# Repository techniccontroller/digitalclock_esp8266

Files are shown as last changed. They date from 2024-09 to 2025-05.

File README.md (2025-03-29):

# DigitalClock

DigitalClick with Neopixel LEDs and ESP8266

More details on my website: https://techniccontroller.com/diy-digitalclock-with-neopixel-led-and-esp8266/ 

## Features
- receives time updates via a NTP server
- automatic switches between summer and winter time
- provides easy WIFI setup with WifiManager
- has a HTML webserver interface for configuration and control
- color of display is configurable
- night mode is configurable (start and end time)
- brightness of LEDs is adjustable
- an automatic current limiting of LEDs protects the power supply
- automatic timezone setting

## Pictures of clock

|  |  |  |
|-|-|-|

## Screenshots of webserver UI

screenshots_UI

## Quickstart

1. Clone the project into the sketch folder of the Arduino IDE, 
2. Install the additional libraries and upload the program to the ESP8266 as usual (See section [*Upload program to ESP8266*](https://github.com/techniccontroller/ringclock_esp8266/blob/main/README.md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) below). 
3. The implemented WiFiManager helps you to set up a WiFi connection with your home WiFi -> on the first startup it will create a WiFi access point named "DigitialClockAP". Connect your phone to this access point and follow the steps which will be shown to you. 
4. After a successful WiFi setup, open the browser and enter the IP address of your ESP8266 to access the interface of the webserver. 
5. Here you can upload all files located in the folder "data". Please make sure all icons stay in the folder "icons" also on the webserver.
    - Open **http://\<ip-address\>/fs.html** in a browser
    - Upload **fs.html**
    - Upload **style.css**
    - Upload **index.html**
    - Create a new folder **icons**
    - Upload all icons into this new folder **icons**

  

## Install needed Libraries

Please download all these libraries as ZIP from GitHub, and extract them in the *libraries* folder of your Sketchbook location (see **File -> Preferences**):

- https://github.com/adafruit/Adafruit_NeoPixel
- https://github.com/tzapu/WiFiManager
- https://github.com/adafruit/Adafruit_BusIO

folder structure should look like this:

```
MySketchbookLocation 
│
└───libraries
│   └───Adafruit_NeoPixel
│   └───WiFiManager
│   └───Adafruit_BusIO
│   
└───digitalclock_esp8266
    │   digitalclock_esp8266.ino
    │   (...)
    |
    └───data
        │   index.html
        |   (...)
        |
        └───icons 
```

## Upload program to ESP8266 with Arduino IDE

#### STEP1: Installation of Arduino IDE
First, the latest version of the Arduino IDE needs to be downloaded and installed from [here](https://www.arduino.cc/en/software).

#### STEP2: Installation of ESP8266 Arduino Core
To program the ESP8266 with the Arduino IDE, you need to install the board information first in Arduino IDE. To do that follow the following instructions:

- Start Arduino and open the File -> Preferences window.

- Enter http://arduino.esp8266.com/stable/package_esp8266com_index.json into the Additional Board Manager URLs field. You can add multiple URLs, separating them with commas.


- Open Boards Manager from Tools > Board menu and search for "esp8266".

- Click the install button.

- Don’t forget to select your ESP8266 board from Tools > Board menu after installation (e.g NodeMCU 1.0, or Wemos D1 mini)


#### STEP3: Upload a program to ESP8266

- Open digitalclock_esp8266.ino in Arduino IDE
- Connect ESP8266 board with Computer
- Select right serial Port in Tools -> Port
- Click on the upload button in the Arduino IDE to upload the program to the ESP8266 Module.     


## Resetting the WiFi configuration

You can clear the stored WiFi credentials and restart the WiFi setup described above with these steps:
1. Open the settings panel in the web UI.
2. Enable 'Reset WiFi' slider.
3. Save settings.
4. Disconnect and reconnect the power. WiFi credentials were removed. The setup should be restarted.
Resetting the wifi credentials does not delete uploaded files.

## Remark about Logging

The Clock sends continuous log messages to the serial port and via multicast UDP. If you want to see these messages, you have to 

- open the serial monitor in the Arduino IDE (Tools -> Serial Monitor). The serial monitor must be set to 115200 baud.

OR

- run the following steps for the multicast UDP logging:

1. Starting situation: Clock is connected to WLAN, a computer with installed Python (https://www.python.org/downloads/) is in the same local area network (WLAN or LAN doesn't matter).
3. Open the file **multicastUDP_receiver.py** in a text editor and in line 81 enter the IP address of the computer (not the clock!).
```python	
# ip address of network interface
MCAST_IF_IP = '192.168.0.7'
```
4. Execute the script with following command: 

```bash
python multicastUDP_receiver.py
```

5. Now you should see the log messages of the clock (every 5 seconds a heartbeat message and the currently displayed time). 
If this is not the case, there could be a problem with the network settings of the computer, then recording is unfortunately not possible.

6. If special events (failed NTP update, reboot) occure, a section of the log is saved in a file called *log.txt*. 
In principle, the events are not critical and will occur from time to time, but should not be too frequent.

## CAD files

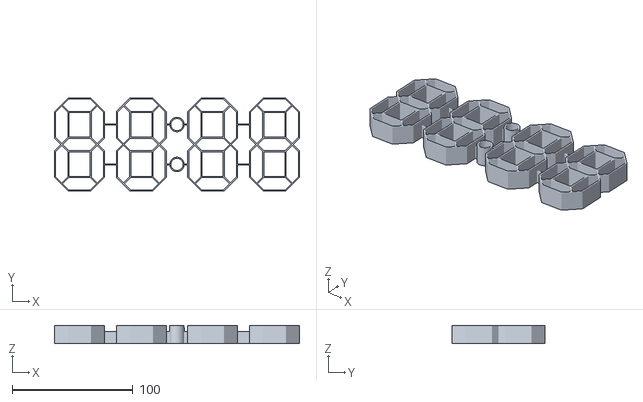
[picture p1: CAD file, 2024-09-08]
CAD_printing_data/digitalclock_7segment_grid.stl
202.5 x 76.8 x 15.0

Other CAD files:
CAD_printing_data/digitalclock_7segment_grid.f3d
CAD_printing_data/digitalclock_backside v3.f3d
CAD_printing_data/digitalclock_frame.f3d
CAD_printing_data/digitalclock_front.f3d

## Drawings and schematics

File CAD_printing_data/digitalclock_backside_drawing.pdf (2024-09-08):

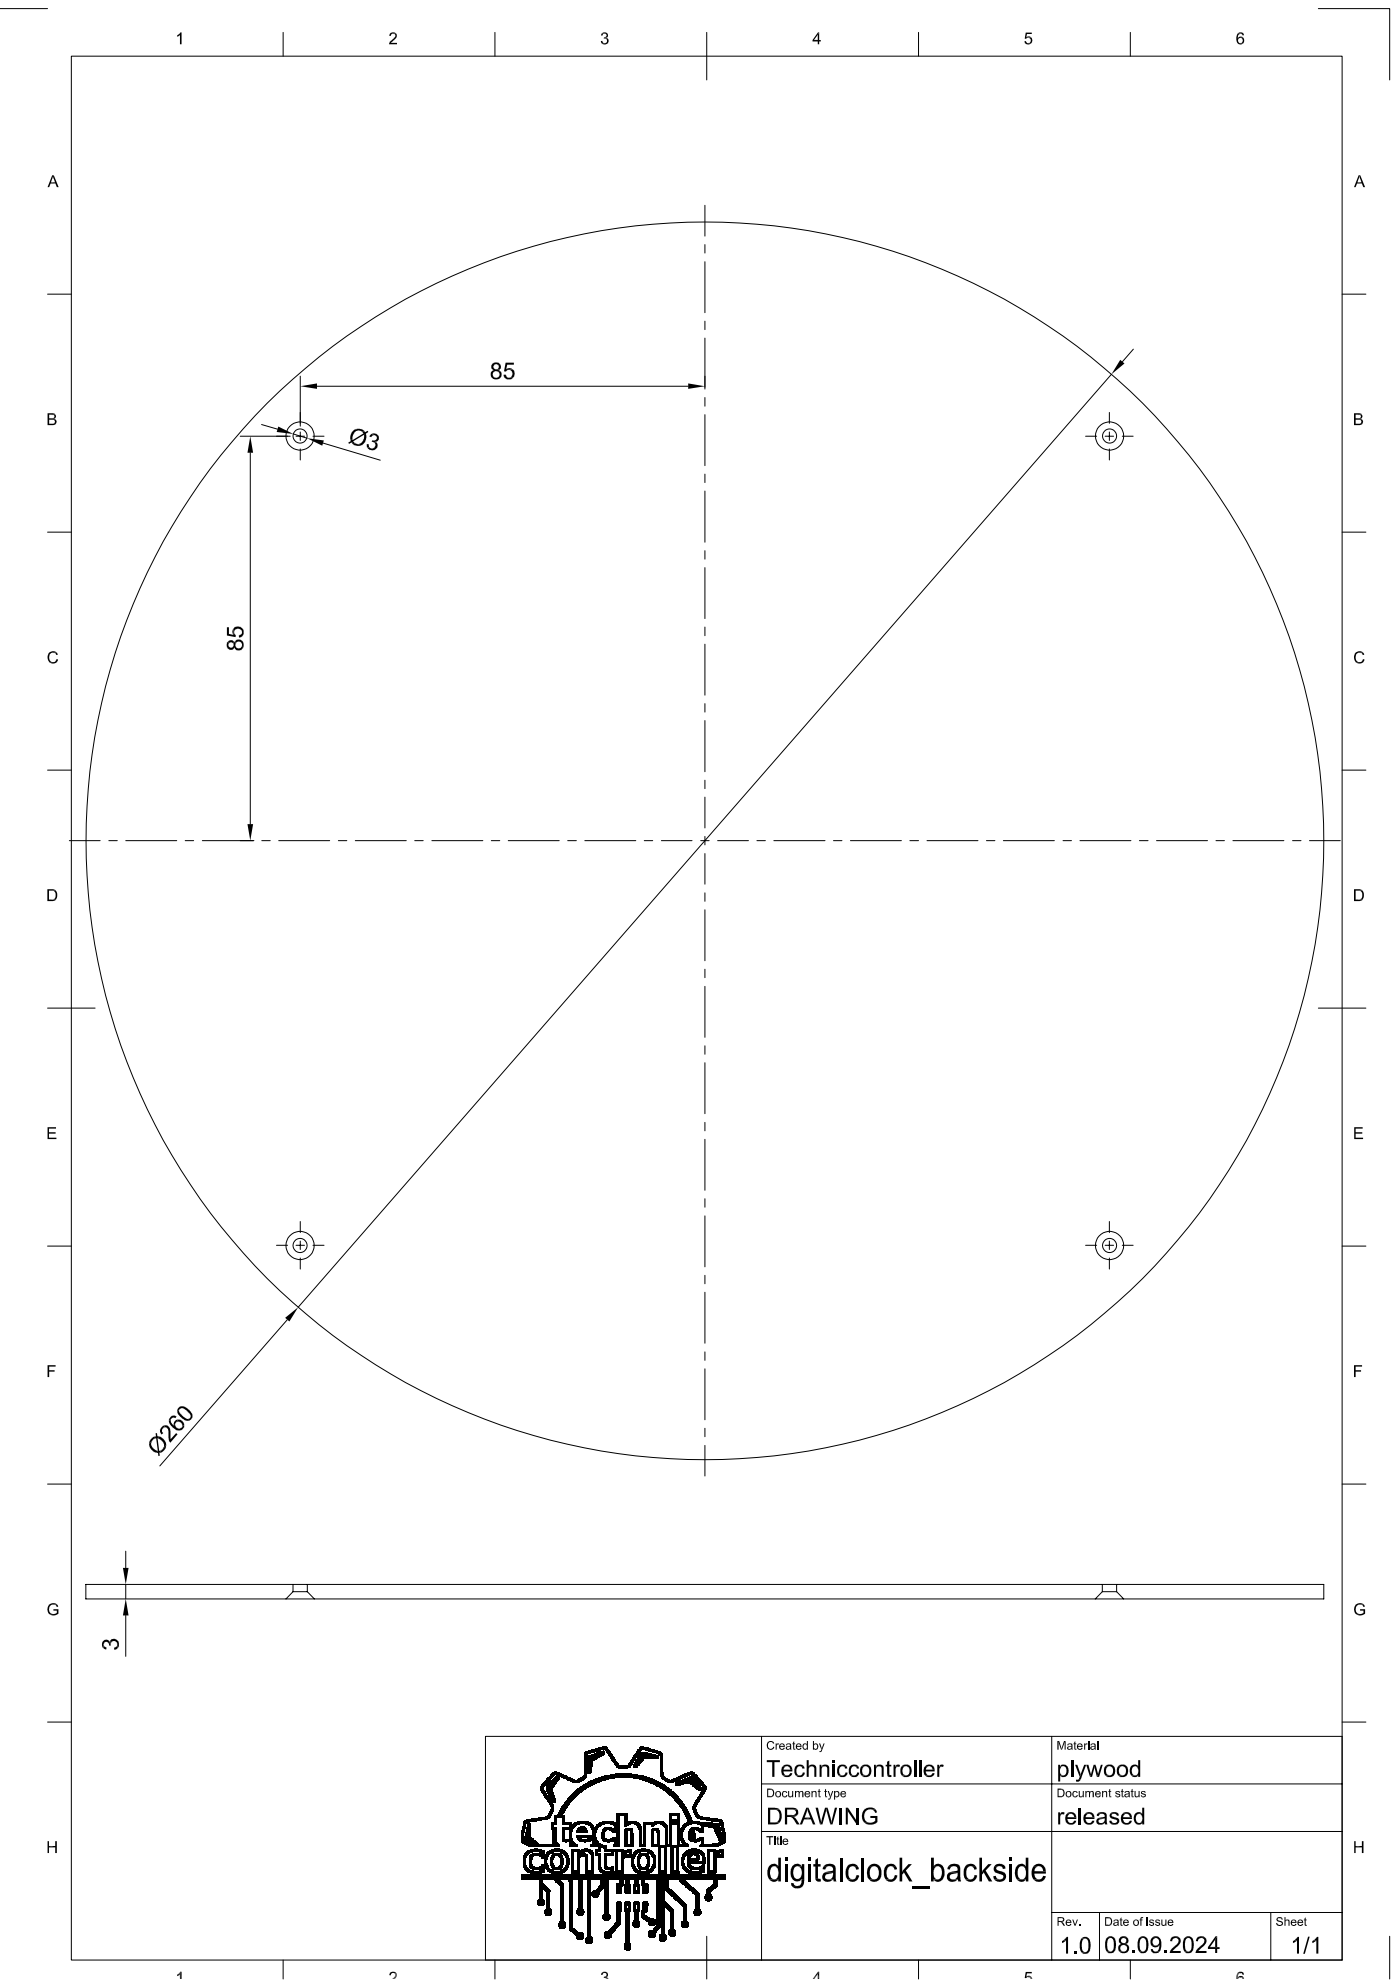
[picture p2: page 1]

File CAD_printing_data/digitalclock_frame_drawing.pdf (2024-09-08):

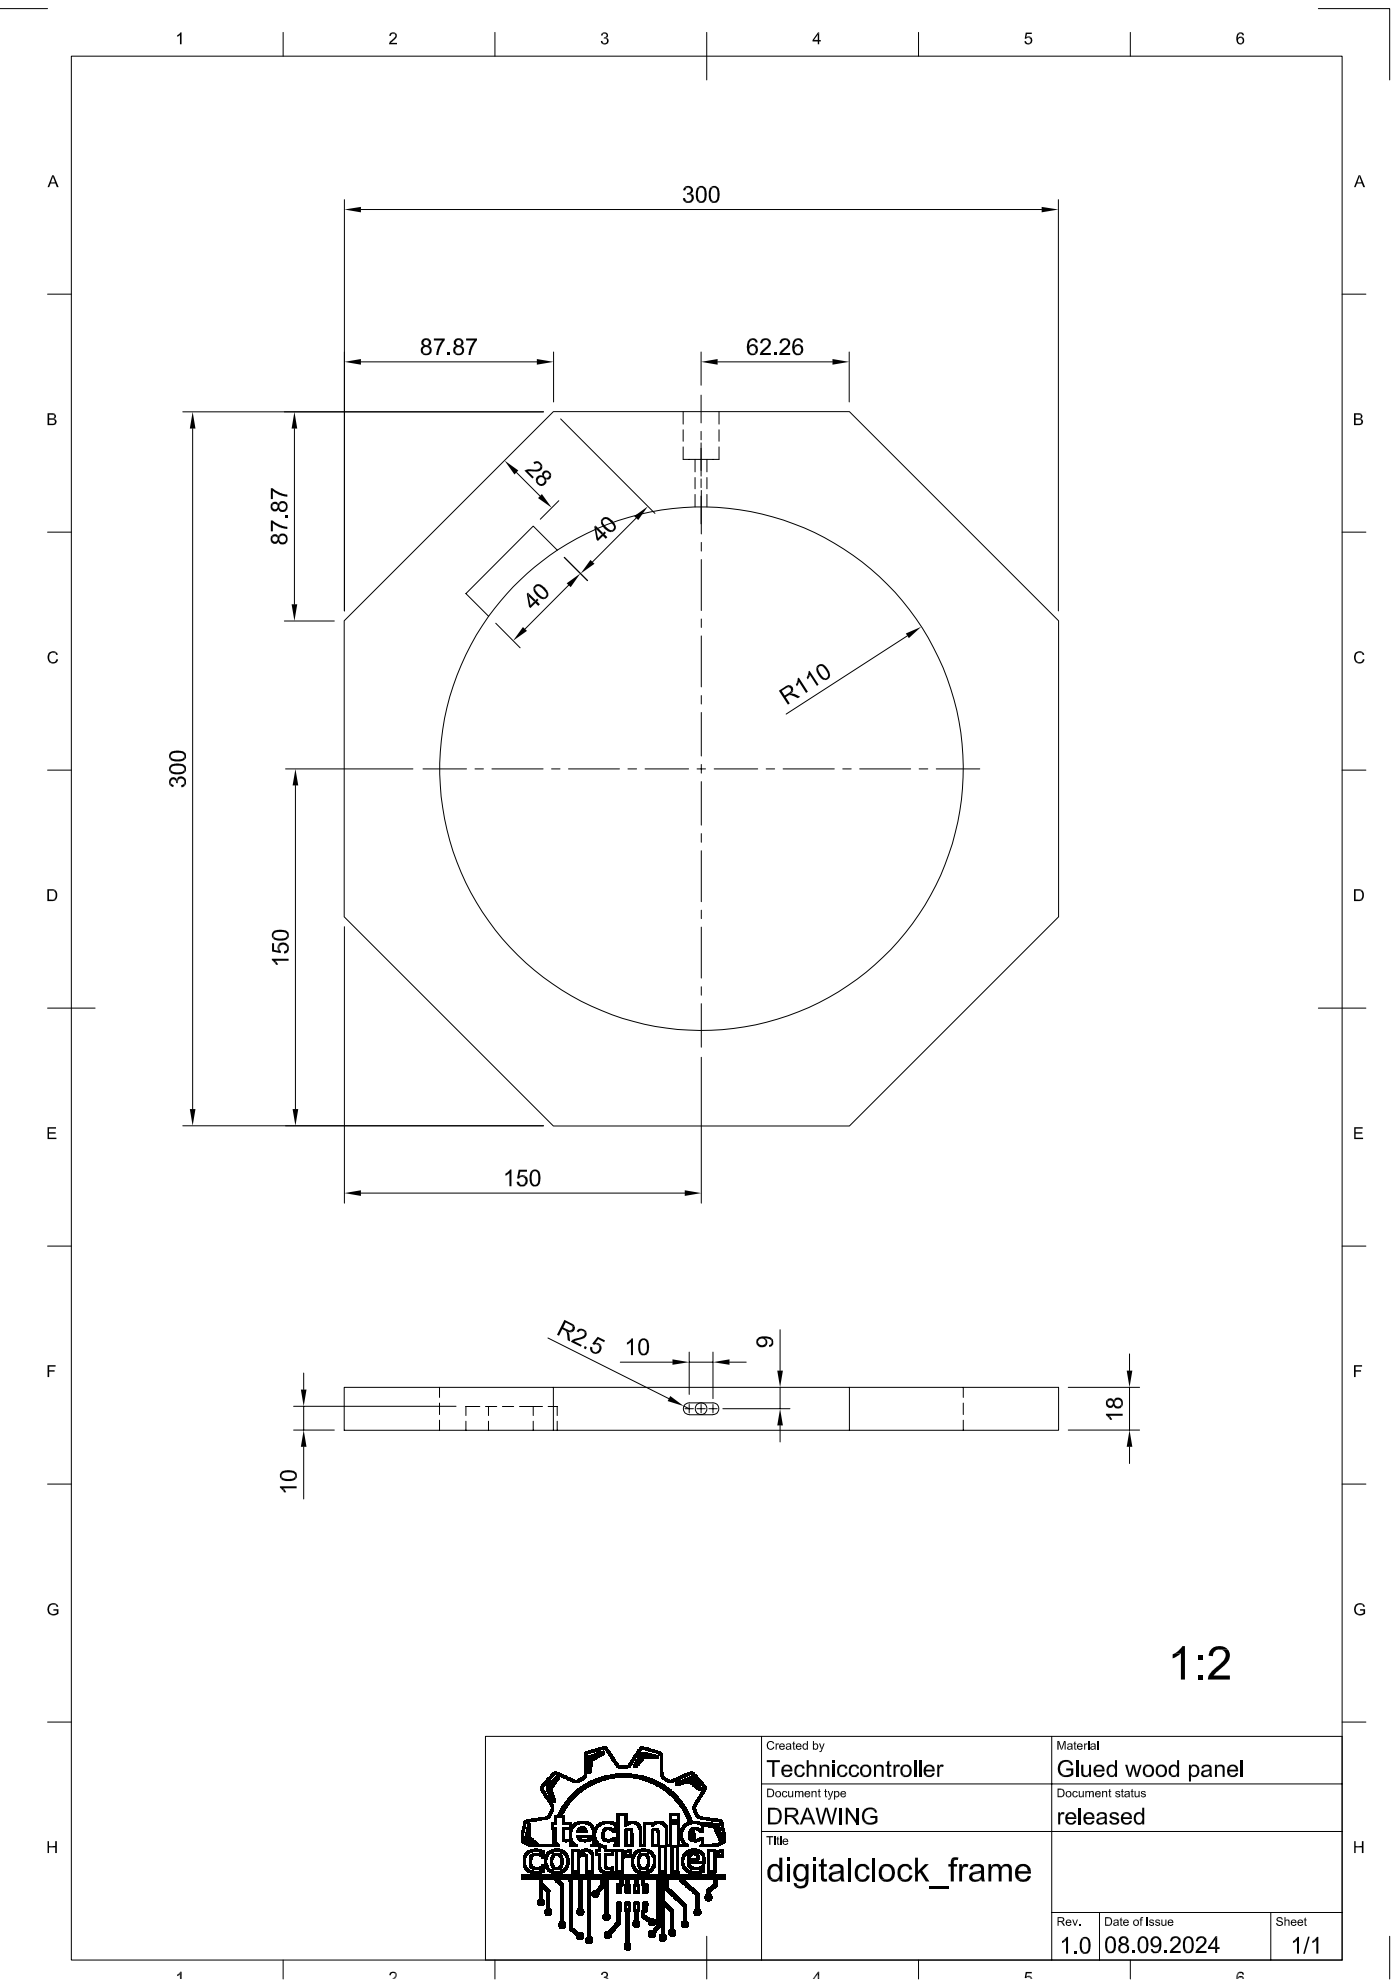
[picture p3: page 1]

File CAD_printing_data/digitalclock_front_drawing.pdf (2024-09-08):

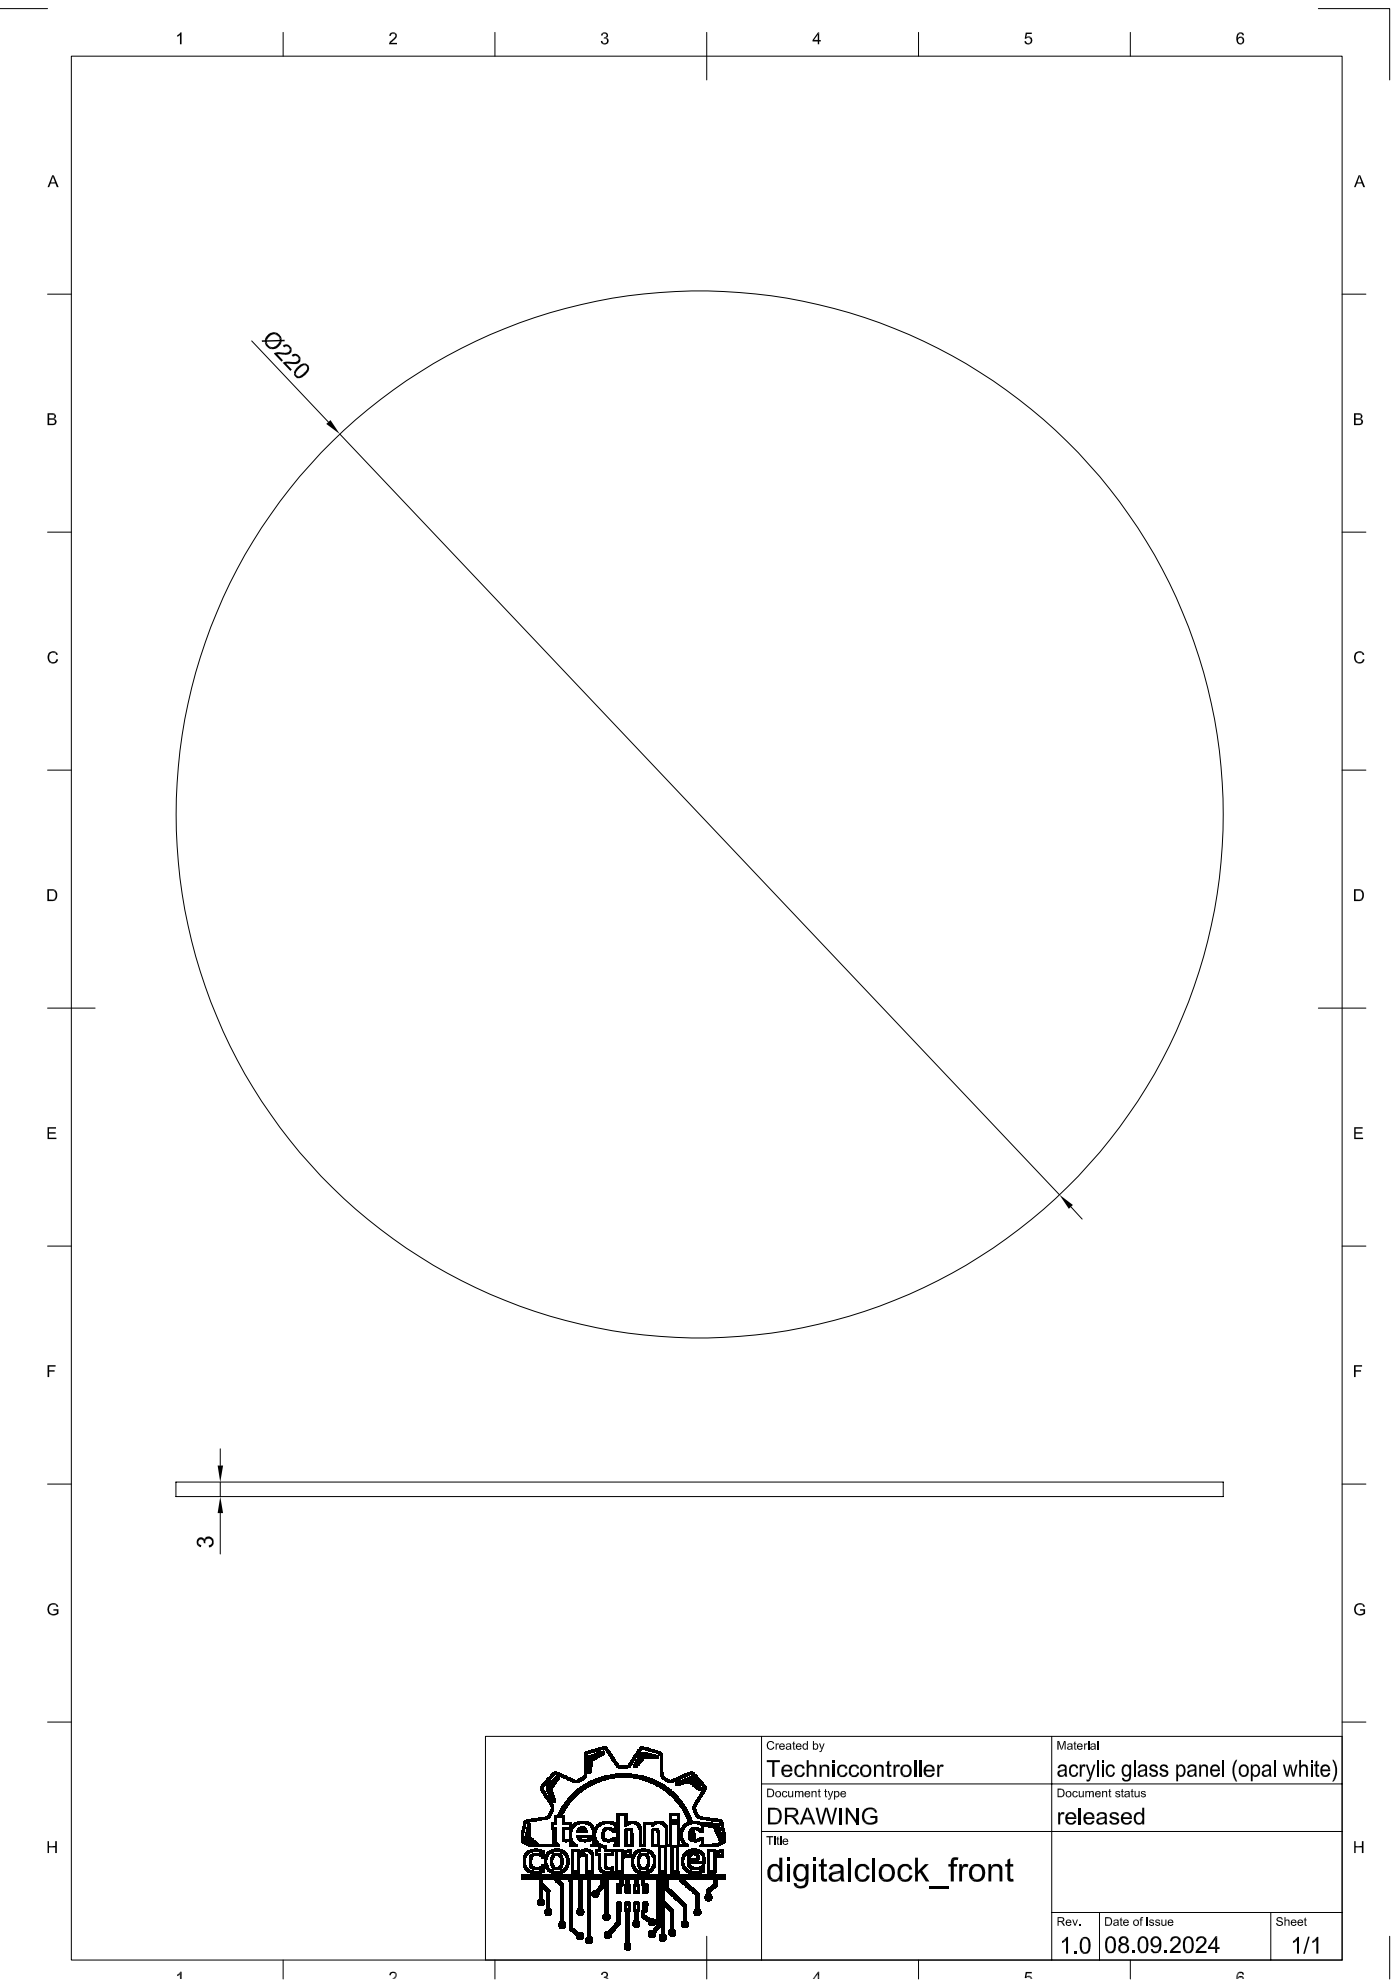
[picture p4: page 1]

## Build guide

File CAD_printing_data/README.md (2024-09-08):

# CAD data for DigitalClock

This folder contains the CAD, STL and drawing files for the DigitalClock parts.
The CAD files can be edited with Autodesk Fusion 360.

Parts:

- **digitalclock_7segment_grid**: Printed with a 3D printer, using the settings below
- **digitalclock_backside**: Cut from 3mm plywood with a jigsaw.
- **digitalclock_frame**: Cut from 18mm wooden board witha a jigsaw.
- **digitalclock_front**: The 3mm acrylic plate was already ordered in correct shape.

## Printer Settings

To ensure optimal printing results, please use the following printer settings:

- Filament: Black PLA
- Nozzle diameter: 1.0 mm
- Layer Height: 0.32 mm
- Infill Density: 20%
- Support Material: none
- Raft/Brim: none

Prinitng with 0.4 mm nozzle is also possible, just takes longer time.

## Pictures

digitalclock_7segment_grid            |  digitalclock_backside | digitalclock_frame | digitalclock_front
:-------------------------:|:-------------------------:|:-------------------------:|:-------------------------:
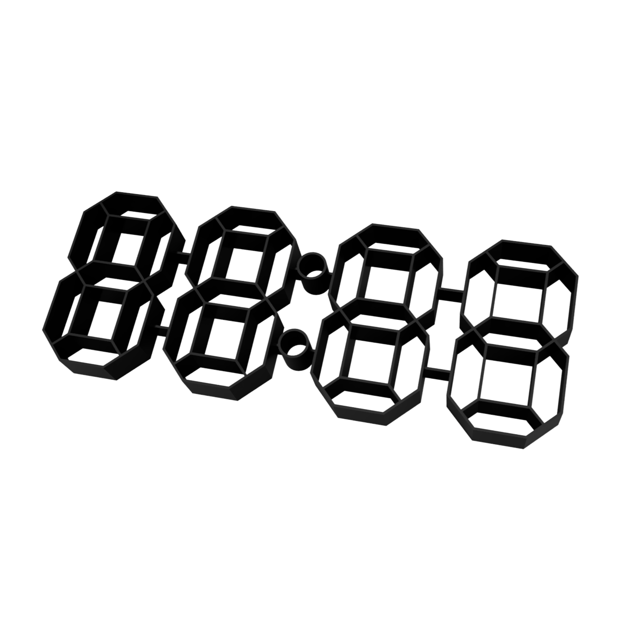
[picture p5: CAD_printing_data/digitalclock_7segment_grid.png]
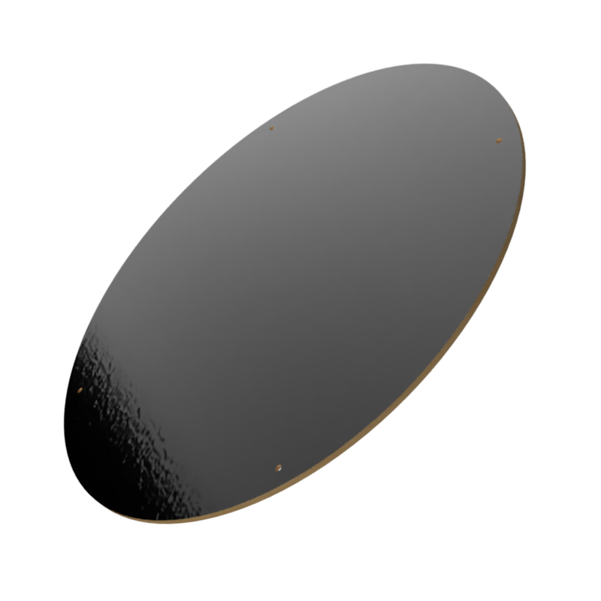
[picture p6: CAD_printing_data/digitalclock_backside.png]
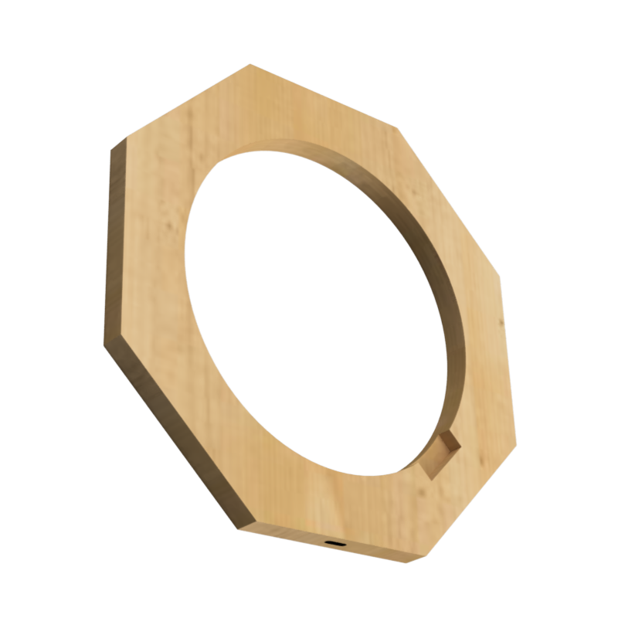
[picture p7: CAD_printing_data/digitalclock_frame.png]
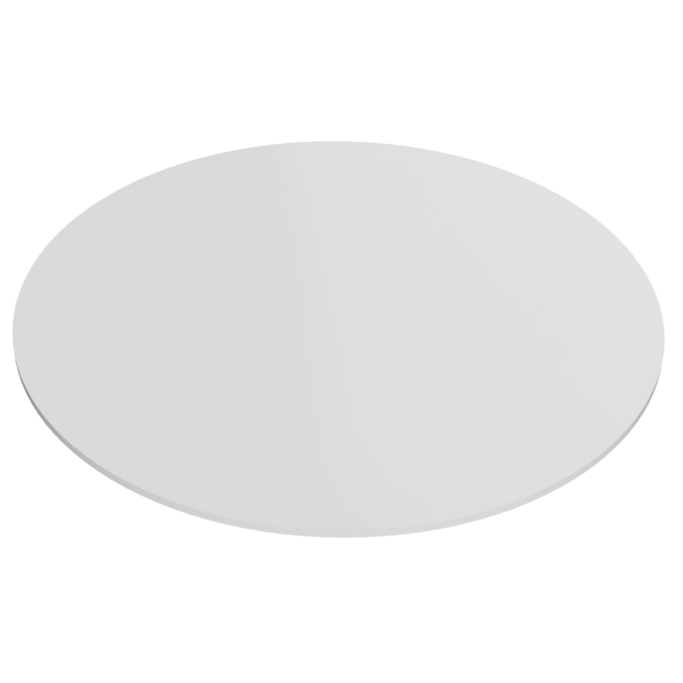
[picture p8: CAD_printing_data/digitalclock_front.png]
 | | |

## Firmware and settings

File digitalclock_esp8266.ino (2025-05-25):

/**
 * Digitalclock - Clock with 7-segment digitis based on NeoPixel with ESP8266 and NTP time update
 * 
 * created by techniccontroller 29.03.2025
 * 
 * components:
 * - ESP8266 (Wemos D1 mini)
 * - 47x NeoPixel WS2812B LED-strip 60/m
 * - 46x NeoPixel WS2812B LED-strip 30/m
 * 
 * Board settings:
 * - Board: LOLIN(WEMOS) D1 mini (clone)
 * - Flash Size: 4MB (FS:2MB OTA:~1019KB)
 * - Upload Speed: 115200
 * 
 * Libraries:
 * - Adafruit NeoPixel
 * - Adafruit GFX
 * - ArduinoOTA
 * - ESP8266WiFi
 * - WiFiManager
*/
#include <LittleFS.h>
#include <Adafruit_NeoPixel.h>          // NeoPixel library used to run the NeoPixel LEDs: https://github.com/adafruit/Adafruit_NeoPixel
#include <ESP8266WiFi.h>
#include <WiFiUdp.h>
#include <ArduinoOTA.h>
#include <ESP8266WebServer.h>
#include <WiFiManager.h>                //https://github.com/tzapu/WiFiManager WiFi Configuration Magic
#include <EEPROM.h>                     //from ESP8266 Arduino Core (automatically installed when ESP8266 was installed via Boardmanager)

// own libraries
#include "constants.h"
#include "udplogger.h"
#include "ntp_client_plus.h"
#include "ledstrip.h"
#include "segment_clock.h"
#include "Arduino.h"

#define DELAYVAL 100

// ports
const unsigned int HTTPPort = 80;
const unsigned int logMulticastPort = 8123;

// ip addresses for multicast logging
IPAddress logMulticastIP = IPAddress(230, 120, 10, 2);

// ip addresses for Access Point
IPAddress IPAdress_AccessPoint(192,168,10,2);
IPAddress Gateway_AccessPoint(192,168,10,0);
IPAddress Subnetmask_AccessPoint(255,255,255,0);

// SSID for Access Point
const char* AP_SSID = "digitalclockAP";

// hostname
const String hostname = "digitalclock";

int utcOffset = 60; // UTC offset in minutes

// ----------------------------------------------------------------------------------
//                                        GLOBAL VARIABLES
// ----------------------------------------------------------------------------------

// Webserver
ESP8266WebServer server(HTTPPort);

// Wifi manager
WiFiManager wifiManager;

// When we setup the NeoPixel library, we tell it how many pixels, and which pin to use to send signals.
// Note that for older NeoPixel strips you might need to change the third parameter--see the strandtest
// example for more information on possible values.
Adafruit_NeoPixel neopixel_leds(LED_COUNT, LED_PIN, NEO_GRB + NEO_KHZ800);

// timestamp variables
long lastheartbeat = millis();      // time of last heartbeat sending
long lastStep = millis();           // time of last clock update
long lastLedStep = millis();  // time of last led update
long lastNTPUpdate = millis() - (PERIOD_NTP_UPDATE-5000);  // time of last NTP update
long lastNightmodeCheck = millis(); // time of last nightmode check
long lastRandomBackground = millis(); // time of last random background change

// Create necessary global objects
UDPLogger logger;
WiFiUDP NTPUDP;
NTPClientPlus ntp = NTPClientPlus(NTPUDP, "pool.ntp.org", utcOffset, true);
LEDStrip ledstrip = LEDStrip(&neopixel_leds, &logger);
SegmentClock segmentClock = SegmentClock(&ledstrip, &logger);

// colors
uint32_t colorTime = LEDStrip::Color24bit(200, 200, 0);    // color of the hours
uint32_t colorBackground = LEDStrip::Color24bit(0, 200, 200);  // color of the minutes

bool nightMode = false;                       // stores state of nightmode
bool ledOff = false;                          // stores state of LED off
// nightmode settings
uint8_t nightModeStartHour = 22;
uint8_t nightModeStartMin = 0;
uint8_t nightModeEndHour = 7;
uint8_t nightModeEndMin = 0;

// Watchdog counter to trigger restart if NTP update was not possible 30 times in a row (5min)
int watchdogCounter = 30;

bool waitForTimeAfterReboot = false; // wait for time update after reboot

// ----------------------------------------------------------------------------------
//                                       SETUP 
// ----------------------------------------------------------------------------------

void setup() {
  Serial.begin(115200);
  delay(100);

  Serial.println();
  Serial.printf("\nSketchname: %s\nBuild: %s\n", (__FILE__), (__TIMESTAMP__));
  Serial.println();

  //Init EEPROM
  EEPROM.begin(EEPROM_SIZE);

  

  ledstrip.initializeStrip();
  ledstrip.setCurrentLimit(CURRENT_LIMIT_LED);



  /** Use WiFiMaanger for handling initial Wifi setup **/

  // Local intialization. Once its business is done, there is no need to keep it around


  // Uncomment and run it once, if you want to erase all the stored information
  //wifiManager.resetSettings();

  // set custom ip for portal
  //wifiManager.setAPStaticIPConfig(IPAdress_AccessPoint, Gateway_AccessPoint, Subnetmask_AccessPoint);

  // set a custom hostname
  wifiManager.setHostname(hostname);

  // fetches ssid and pass from eeprom and tries to connect
  // if it does not connect it starts an access point with the specified name
  // here "digitalclockAP"
  // and goes into a blocking loop awaiting configuration
  wifiManager.autoConnect(AP_SSID);

  // if you get here you have connected to the WiFi
  Serial.println("Connected.");
  Serial.println("IP address: ");
  Serial.println(WiFi.localIP());

  // init ESP8266 File manager (LittleFS)
  setupFS();

  setupOTA(hostname); 

  server.on("/data", handleDataRequest); // process datarequests
  server.on("/cmd", handleCommand); // process commands
  server.begin();

  // create UDP Logger to send logging messages via UDP multicast
  logger = UDPLogger(WiFi.localIP(), logMulticastIP, logMulticastPort);
  logger.setName("Digitalclock");
  logger.logString("Start program\n");
  logger.logString("Sketchname: "+ String(__FILE__));
  logger.logString("Build: " + String(__TIMESTAMP__));
  logger.logString("IP: " + WiFi.localIP().toString());
  logger.logString("Reset Reason: " + ESP.getResetReason());

  loadColorsFromEEPROM();
  loadNightmodeSettingsFromEEPROM();
  loadBrightnessSettingsFromEEPROM();

  if(ESP.getResetReason().equals("Power On") || ESP.getResetReason().equals("External System")){
    ledstrip.runLEDTest();

    // display IP
    uint8_t address = WiFi.localIP()[3];
    uint8_t first_digit = address/100;
    uint8_t second_digit = (address/10)%10;
    uint8_t third_digit = address%10;

    segmentClock.setTime(first_digit, second_digit * 10 + third_digit);
    ledstrip.drawOnLEDsInstant();
    delay(3000);

    // clear matrix
    ledstrip.flush();
    ledstrip.drawOnLEDsInstant();
  }
  else {
    waitForTimeAfterReboot = true;
  }

  delay(2000);

  // setup NTP
  updateUTCOffsetFromTimezoneAPI(logger, ntp);
  ntp.setupNTPClient();
  logger.logString("NTP running");
  logger.logString("Time: " +  ntp.getFormattedTime());
}

// ----------------------------------------------------------------------------------
//                                       LOOP
// ----------------------------------------------------------------------------------
void loop() {

  // handle OTA
  handleOTA();

  // handle Webserver
  server.handleClient();

  // send regularly heartbeat messages via UDP multicast
  if(millis() - lastheartbeat > PERIOD_HEARTBEAT){
    logger.logString("Heartbeat, FreeHeap: " + String(ESP.getFreeHeap()) 
                      + ", HeapFrag: " + String(ESP.getHeapFragmentation()) 
                      + ", MaxFreeBlock: " + String(ESP.getMaxFreeBlockSize()) + "\n");
    lastheartbeat = millis();
  }

  if((millis() - lastStep > PERIOD_CLOCK_UPDATE) && !nightMode && !ledOff){
    // update LEDs
    updateClock();
    lastStep = millis();
  }

  // Turn off LEDs if ledOff is true or nightmode is active
  if((ledOff || nightMode) && !waitForTimeAfterReboot){
    ledstrip.flush();
    ledstrip.drawOnLEDsInstant();
  }
  // periodically write colors to leds
  else if(millis() - lastLedStep > PERIOD_LED_UPDATE && !waitForTimeAfterReboot){
    ledstrip.drawOnLEDsSmooth(0.2);
    lastLedStep = millis();
  }
  
  if(!ledOff && !nightMode && millis() - lastRandomBackground > PERIOD_BACKGROUND_RANDOM){
    segmentClock.randomizeBackground();
    ledstrip.drawOnLEDsInstant();
    lastRandomBackground = millis();
  }

  // NTP time update
  if(millis() - lastNTPUpdate > PERIOD_NTP_UPDATE){
    int res = ntp.updateNTP();
    if(res == 0){
      ntp.calcDate();
      logger.logString("NTP-Update successful");
      logger.logString("Time: " +  ntp.getFormattedTime());
      logger.logString("Date: " +  ntp.getFormattedDate());
      logger.logString("Day of Week (Mon=1, Sun=7): " +  String(ntp.getDayOfWeek()));
      logger.logString("Summertime: " + String(ntp.updateSWChange()));
      lastNTPUpdate = millis();
      watchdogCounter = 30;
      checkNightmode();
      if(waitForTimeAfterReboot && !nightMode){
        updateClock();
        ledstrip.drawOnLEDsInstant();
      }
      waitForTimeAfterReboot = false;
    }
    else if(res == -1){
      logger.logString("NTP-Update not successful. Reason: Timeout");
      lastNTPUpdate += 10000;
      watchdogCounter--;
    }
    else if(res == 1){
      logger.logString("NTP-Update not successful. Reason: Too large time difference");
      logger.logString("Time: " +  ntp.getFormattedTime());
      logger.logString("Date: " +  ntp.getFormattedDate());
      logger.logString("Day of Week (Mon=1, Sun=7): " +  ntp.getDayOfWeek());
      logger.logString("Summertime: " + String(ntp.updateSWChange()));
      lastNTPUpdate += 10000;
      watchdogCounter--;
    }
    else {
      logger.logString("NTP-Update not successful. Reason: NTP time not valid (<1970)");
      lastNTPUpdate += 10000;
      watchdogCounter--;
    }

    logger.logString("Watchdog Counter: " + String(watchdogCounter));
    if(watchdogCounter <= 0){
        logger.logString("Trigger restart due to watchdog...");
        delay(100);
        ESP.restart();
    }
    
  }

  // check if nightmode need to be activated
  if(millis() - lastNightmodeCheck > PERIOD_NIGHTMODE_CHECK && !waitForTimeAfterReboot){
    checkNightmode(); 
    lastNightmodeCheck = millis();
  }

}

// ----------------------------------------------------------------------------------
//                                       FUNCTIONS
// ----------------------------------------------------------------------------------

/**
 * @brief Clock update
*/
void updateClock(){
  int hours = ntp.getHours24();
  int minutes = ntp.getMinutes();
  segmentClock.setTimeColor(colorTime);
  segmentClock.setBackgroundColor(colorBackground);
  segmentClock.setTime(hours, minutes);
}

/**
 * @brief Check if nightmode should be activated
 */
void checkNightmode(){
  logger.logString("Check nightmode");
  int hours = ntp.getHours24();
  int minutes = ntp.getMinutes();

  nightMode = false; // Initial assumption

  // Convert all times to minutes for easier comparison
  int currentTimeInMinutes = hours * 60 + minutes;
  int startInMinutes = nightModeStartHour * 60 + nightModeStartMin;
  int endInMinutes = nightModeEndHour * 60 + nightModeEndMin;

  if (startInMinutes < endInMinutes) { // Same day scenario
      if (startInMinutes < currentTimeInMinutes && currentTimeInMinutes < endInMinutes) {
          nightMode = true;
          logger.logString("Nightmode activated");
      }
  } else if (startInMinutes > endInMinutes) { // Overnight scenario
      if (currentTimeInMinutes >= startInMinutes || currentTimeInMinutes < endInMinutes) {
          nightMode = true;
          logger.logString("Nightmode activated");
      }
  }
}

/**
 * @brief Load the colors for hours, minutes and seconds from EEPROM
*/
void loadColorsFromEEPROM(){
  colorTime = getRGBColorFromEEPROM(ADR_TI_RED, ADR_TI_GREEN, ADR_TI_BLUE);
  colorBackground = getRGBColorFromEEPROM(ADR_BG_RED, ADR_BG_GREEN, ADR_BG_BLUE);
}

/**
 * @brief Load a color from EEPROM
 * 
 * @param adr_red address of red value in EEPROM
 * @param adr_green address of green value in EEPROM
 * @param adr_blue address of blue value in EEPROM
 * 
 * @return color as 24bit integer
*/
uint32_t getRGBColorFromEEPROM(uint8_t adr_red, uint8_t adr_green, uint8_t adr_blue){
  uint8_t red = EEPROM.read(adr_red);
  uint8_t green = EEPROM.read(adr_green);
  uint8_t blue = EEPROM.read(adr_blue);
  if(int(red) + int(green) + int(blue) < 50){
    return LEDStrip::Color24bit(200, 200, 0);
  } else {
    return LEDStrip::Color24bit(red, green, blue);
  }
}

/**
 * @brief Load the nightmode settings from EEPROM
*/
void loadNightmodeSettingsFromEEPROM()
{
  nightModeStartHour = EEPROM.read(ADR_NM_START_H);
  nightModeStartMin = EEPROM.read(ADR_NM_START_M);
  nightModeEndHour = EEPROM.read(ADR_NM_END_H);
  nightModeEndMin = EEPROM.read(ADR_NM_END_M);
  if (nightModeStartHour > 23)
    nightModeStartHour = 22; // set to 22 o'clock as default
  if (nightModeStartMin > 59)
    nightModeStartMin = 0;
  if (nightModeEndHour > 23)
    nightModeEndHour = 7; // set to 7 o'clock as default
  if (nightModeEndMin > 59)
    nightModeEndMin = 0;
  logger.logString("Nightmode starts at: " + String(nightModeStartHour) + ":" + String(nightModeStartMin));
  logger.logString("Nightmode ends at: " + String(nightModeEndHour) + ":" + String(nightModeEndMin));
}

/**
 * @brief Load the brightness settings from EEPROM
 * 
 * lower limit is 10 so that the LEDs are not completely off
*/
void loadBrightnessSettingsFromEEPROM()
{
  uint8_t brightnessTime = EEPROM.read(ADR_BRIGHTNESS_TIME);
  uint8_t brightnessBackground = EEPROM.read(ADR_BRIGHTNESS_BACKGROUND);
  float speedBackground = EEPROM.read(ADR_SPEED_BACKGROUND) / 100.0; // read speed as percentage
  if (brightnessTime < 10)
    brightnessTime = 10;
  if (brightnessBackground < 10)
    brightnessBackground = 10;
  if (speedBackground < 0.2)
    speedBackground = 0.2; // set minimum speed to 0.2
  segmentClock.setTimeBrightness(brightnessTime);
  segmentClock.setBackgroundBrightness(brightnessBackground);
  segmentClock.setBackgroundAnimationSpeed(speedBackground);
  logger.logString("BrightnessTime: " + String(brightnessTime) + ", BrightnessBackround: " + String(brightnessBackground)
                   + ", SpeedBackground: " + String(speedBackground));
}

/**
 * @brief Set the color for hours
 * 
 * @param red red value
 * @param green green value
 * @param blue blue value
*/
void setColorTime(uint8_t red, uint8_t green, uint8_t blue){
  colorTime = LEDStrip::Color24bit(red, green, blue);
  EEPROM.write(ADR_TI_RED, red);
  EEPROM.write(ADR_TI_GREEN, green);
  EEPROM.write(ADR_TI_BLUE, blue);
  EEPROM.commit();
}

/**
 * @brief Set the color for minutes
 * 
 * @param red red value
 * @param green green value
 * @param blue blue value
*/
void setColorBackround(uint8_t red, uint8_t green, uint8_t blue){
  colorBackground = LEDStrip::Color24bit(red, green, blue);
  EEPROM.write(ADR_BG_RED, red);
  EEPROM.write(ADR_BG_GREEN, green);
  EEPROM.write(ADR_BG_BLUE, blue);
  EEPROM.commit();
}

/**
 * @brief Handler for handling commands sent to "/cmd" url
 * 
 */
void handleCommand() {
  // receive command and handle accordingly
  for (uint8_t i = 0; i < server.args(); i++) {
    String log_str = "Command received: " + server.argName(i) + " " + server.arg(i);
    logger.logString(log_str);
  }
  
  if (server.argName(0) == "col_time") // the parameter which was sent to this server is the color for time
  {
    String colorstr = server.arg(0) + "-";
    String redstr = split(colorstr, '-', 0);
    String greenstr= split(colorstr, '-', 1);
    String bluestr = split(colorstr, '-', 2);
    logger.logString(colorstr);
    logger.logString("r: " + String(redstr.toInt()));
    logger.logString("g: " + String(greenstr.toInt()));
    logger.logString("b: " + String(bluestr.toInt()));
    setColorTime(redstr.toInt(), greenstr.toInt(), bluestr.toInt());
  }
  else if (server.argName(0) == "col_background") // the parameter which was sent to this server is the color for background
  {
    String colorstr = server.arg(0) + "-";
    String redstr = split(colorstr, '-', 0);
    String greenstr= split(colorstr, '-', 1);
    String bluestr = split(colorstr, '-', 2);
    logger.logString(colorstr);
    logger.logString("r: " + String(redstr.toInt()));
    logger.logString("g: " + String(greenstr.toInt()));
    logger.logString("b: " + String(bluestr.toInt()));
    setColorBackround(redstr.toInt(), greenstr.toInt(), bluestr.toInt());
  }
  else if(server.argName(0) == "ledoff"){
    String modestr = server.arg(0);
    logger.logString("LED off change via Webserver to: " + modestr);
    if(modestr == "1") ledOff = true;
    else ledOff = false;
  }
  else if(server.argName(0) == "setting"){
    String timestr = server.arg(0) + "-";
    logger.logString("Nightmode setting change via Webserver to: " + timestr);
    nightModeStartHour = split(timestr, '-', 0).toInt();
    nightModeStartMin = split(timestr, '-', 1).toInt();
    nightModeEndHour = split(timestr, '-', 2).toInt();
    nightModeEndMin = split(timestr, '-', 3).toInt();
    uint8_t brightnessTime = split(timestr, '-', 4).toInt();
    uint8_t brightnessBackground = split(timestr, '-', 5).toInt();
    float speedBackground = split(timestr, '-', 6).toFloat();
    if(nightModeStartHour > 23) nightModeStartHour = 22; // set default
    if(nightModeStartMin > 59) nightModeStartMin = 0;
    if(nightModeEndHour > 23) nightModeEndHour = 7; // set default
    if(nightModeEndMin > 59) nightModeEndMin = 0;
    if(brightnessTime < 10) brightnessTime = 10;
    if(brightnessBackground < 10) brightnessBackground = 10;
    if(speedBackground < 0.2) speedBackground = 0.2; // set minimum speed
    EEPROM.write(ADR_NM_START_H, nightModeStartHour);
    EEPROM.write(ADR_NM_START_M, nightModeStartMin);
    EEPROM.write(ADR_NM_END_H, nightModeEndHour);
    EEPROM.write(ADR_NM_END_M, nightModeEndMin);
    EEPROM.write(ADR_BRIGHTNESS_TIME, brightnessTime);
    EEPROM.write(ADR_BRIGHTNESS_BACKGROUND, brightnessBackground);
    EEPROM.write(ADR_SPEED_BACKGROUND, (uint8_t)(speedBackground * 100)); // store speed as percentage
    EEPROM.commit();
    logger.logString("Nightmode starts at: " + String(nightModeStartHour) + ":" + String(nightModeStartMin));
    logger.logString("Nightmode ends at: " + String(nightModeEndHour) + ":" + String(nightModeEndMin));
    logger.logString("BrightnessTime: " + String(brightnessTime) + ", BrightnessBackground: " + String(brightnessBackground));
    logger.logString("SpeedBackground: " + String(speedBackground));
    segmentClock.setTimeBrightness(brightnessTime);
    segmentClock.setBackgroundBrightness(brightnessBackground);
    segmentClock.setBackgroundAnimationSpeed(speedBackground);
    lastNightmodeCheck = 0;
  }
  else if (server.argName(0) == "resetwifi"){
    logger.logString("Reset Wifi via Webserver...");
    wifiManager.resetSettings();
    ledstrip.runLEDTest();
  }
  else if (server.argName(0) == "reboot"){
    logger.logString("Reboot via Webserver...");
    server.send(204, "text/plain", "No Content"); // this page doesn't send back content --> 204
    delay(1000);
    ESP.restart();
  }
  
  server.send(204, "text/plain", "No Content"); // this page doesn't send back content --> 204
}

/**
 * @brief Splits a string at given character and return specified element
 * 
 * @param s string to split
 * @param parser separating character
 * @param index index of the element to return
 * @return String 
 */
String split(String s, char parser, int index) {
  String rs="";
  int parserCnt=0;
  int rFromIndex=0, rToIndex=-1;
  while (index >= parserCnt) {
    rFromIndex = rToIndex+1;
    rToIndex = s.indexOf(parser,rFromIndex);
    if (index == parserCnt) {
      if (rToIndex == 0 || rToIndex == -1) return "";
      return s.substring(rFromIndex,rToIndex);
    } else parserCnt++;
  }
  return rs;
}

/**
 * @brief Handler for GET requests
 * 
 */
void handleDataRequest() {
  // receive data request and handle accordingly
  for (uint8_t i = 0; i < server.args(); i++) {
    String log_str = "Command received: " + server.argName(i) + " " + server.arg(i);
    logger.logString(log_str);
  }
  
  if (server.argName(0) == "key") // the parameter which was sent to this server is led color
  {
    String message = "{";
    String keystr = server.arg(0);
    if(keystr == "mode"){
      message += "\"ledoff\":\"" + String(ledOff) + "\"";
      message += ",";
      message += "\"nightMode\":\"" + String(nightMode) + "\"";
      message += ",";
      message += "\"nightModeStart\":\"" + leadingZero2Digit(nightModeStartHour) + "-" + leadingZero2Digit(nightModeStartMin) + "\"";
      message += ",";
      message += "\"nightModeEnd\":\"" + leadingZero2Digit(nightModeEndHour) + "-" + leadingZero2Digit(nightModeEndMin) + "\"";
      message += ",";
      message += "\"brightnessTime\":\"" + String(segmentClock.getBrightnessTime()) + "\"";
      message += ",";
      message += "\"brightnessBackground\":\"" + String(segmentClock.getBrightnessBackground()) + "\"";
      message += ",";
      message += "\"speedBackground\":\"" + String(segmentClock.getBackgroundAnimationSpeed()) + "\"";
    }
    message += "}";
    logger.logString(message);
    server.send(200, "application/json", message);
  }
}

/**
 * @brief Convert Integer to String with leading zero
 * 
 * @param value 
 * @return String 
 */
String leadingZero2Digit(int value){
  String msg = "";
  if(value < 10){
    msg = "0";
  }
  msg += String(value);
  return msg;
}

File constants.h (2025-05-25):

#define LED_COUNT 93
#define LED_PIN 5
#define CURRENT_LIMIT_LED 1000

#define PERIOD_HEARTBEAT 10000
#define PERIOD_NTP_UPDATE 60000
#define PERIOD_CLOCK_UPDATE 20
#define PERIOD_LED_UPDATE 100
#define PERIOD_NIGHTMODE_CHECK 20000
#define PERIOD_BACKGROUND_RANDOM 20

#define EEPROM_SIZE 30      // size of EEPROM to save persistent variables
#define ADR_NM_START_H 0
#define ADR_NM_END_H 4
#define ADR_NM_START_M 8
#define ADR_NM_END_M 12
#define ADR_BRIGHTNESS_BACKGROUND 16
#define ADR_BRIGHTNESS_TIME 17
#define ADR_SPEED_BACKGROUND 18
#define ADR_BG_RED 21
#define ADR_BG_GREEN 22
#define ADR_BG_BLUE 23
#define ADR_TI_RED 24
#define ADR_TI_GREEN 25
#define ADR_TI_BLUE 26

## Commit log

2024-09-02 set led update period to 100ms
2024-09-08 add CAD files
    [digitalclock_7segment_grid.f3d, digitalclock_7segment_grid.stl, digitalclock_backside v3.f3d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]
2024-09-08 adjust condition when to show the led test
2024-11-10 add filter function for log receiver
2024-11-10 fix silent reboot feature if clock reboots due to watchdog or crash, its not noticable by user
    [digitalclock_esp8266.ino]
2025-03-29 Refactor multicastUDP_receiver to support multiple filters and improve logging functionality
